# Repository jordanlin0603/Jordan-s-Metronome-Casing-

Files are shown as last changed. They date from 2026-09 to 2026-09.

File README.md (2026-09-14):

# Jordan's Metronome Casing

A custom SolidWorks enclosure designed for [Morgan's Metronome v1.0](https://github.com/morganwang7777-ux/Morgan-s-Metronome-v1.0).

This project focuses on the mechanical design of the metronome enclosure. The casing houses the main PCB and secondary plate, provides clearance for internal wiring, and uses movable retaining rails to keep the electronics secured while still allowing the PCB to be removed for maintenance.

The enclosure was first explored in AutoCAD before being rebuilt and developed more extensively in SolidWorks.

---

# Final Design

The final casing includes:

- Tapered SolidWorks enclosure
- **100 mm × 90 mm × 30 mm** main PCB cavity
- **71 mm × 55 mm × 15 mm** secondary plate slot
- Wiring-clearance pocket
- Through-enclosure wiring passage
- Two movable PCB retaining rails
- M3 screw-compatible pivot points
- Mechanical stops for the retaining rails
- Removable access to the PCB and internal components

Final design reference: **Solidworks 15**

All SolidWorks design images can be found under:

`Design Progress/SolidWorks`

---

# Design Origin

This enclosure was designed specifically for:

## Morgan's Metronome v1.0

https://github.com/morganwang7777-ux/Morgan-s-Metronome-v1.0

Morgan's project contains the electronic portion of the metronome, including:

- Arduino firmware
- KiCad schematic
- PCB layout
- Gerber manufacturing files
- Metronome electronics
- Controls and display
- Supporting project documentation

This repository focuses on the **mechanical casing, internal mounting geometry, wire routing, and PCB retention system** for that project.

---

# SolidWorks Design Process

The final casing was developed over five main SolidWorks design sessions.

## Day 1 — Main Enclosure and PCB Cavity

Created the tapered metronome body and main PCB cavity.

Design references:

- **Solidworks 1** — Main enclosure
- **Solidworks 2** — PCB cavity

---

## Day 2 — Secondary Plate and Wiring Clearance

Added the secondary plate slot, wiring clearance pocket, and through-enclosure wiring passage.

Design references:

- **Solidworks 3** — Plate cavity
- **Solidworks 4** — Secondary plate slot
- **Solidworks 5** — Wiring clearance
- **Solidworks 6** — Wiring passage

---

## Day 3 — Initial PCB Retaining Rail

Designed the original rotating PCB retaining rail and M3 pivot system.

Design references:

- **Solidworks 7** — Initial retaining rail
- **Solidworks 8** — Rail design

---

## Day 4 — Assembly Testing and Retention Redesign

Created a SolidWorks assembly to test the original retaining rail.

Testing showed that placing one rail across the center of the PCB would obstruct access to the PCB controls.

The retention system was redesigned to use separate rails along the **top and bottom edges**, keeping the middle of the PCB accessible.

Design references:

- **Solidworks 9** — Initial assembly
- **Solidworks 10** — Initial rail test
- **Solidworks 11** — Rail redesign
- **Solidworks 12** — Updated assembly
- **Solidworks 13** — Final rail positions

A retaining rail movement test is also included in the SolidWorks folder.

---

## Day 5 — Mechanical Stops and Final Assembly

Added cylindrical mechanical stops to limit the rotation of the retaining rails and completed the final assembly.

Design reference:

- **Solidworks 14** — Mechanical stops

---

# Final Product

The final SolidWorks enclosure combines the PCB cavity, secondary plate cavity, wiring features, movable retaining rails, and mechanical stops into a single mechanical design.

Final design reference:

- **Solidworks 15**

The SolidWorks assembly, design screenshots, and retaining rail motion test can all be found under:

`Design Progress/SolidWorks`

---

# Main Dimensions

| Feature | Dimension |
| --- | --- |
| Enclosure height | 160 mm |
| Bottom width | 140 mm |
| Top width | 100 mm |
| Main PCB cavity | 100 mm × 90 mm × 30 mm |
| Secondary plate slot | 71 mm × 55 mm × 15 mm |
| Wiring clearance pocket | 10 mm × 18 mm × 21 mm |
| Wiring passage | 14 mm × 10 mm |
| Main retaining rail | 125 mm × 12 mm × 4 mm |
| Secondary retaining rail | 110 mm × 12 mm × 4 mm |
| M3 rail clearance hole | Approximately Ø3.2 mm |
| Casing pilot hole | Approximately Ø2.8 mm × 8 mm |

---

# Retaining System

The PCB is held in the rear cavity using two rotating retaining rails.

The original design used one rail across the center of the PCB. SolidWorks assembly testing showed that this would obstruct access to buttons and other PCB components.

The system was redesigned to use separate **top and bottom rails**.

Each rail rotates around an M3 screw pivot, allowing it to swing away during PCB installation or removal and rotate back into position to retain the board.

Mechanical stops were added to limit the rail movement in the closed position.

---

# SolidWorks Tools Used

- Sketch
- Smart Dimension
- Rectangle
- Circle
- Boss-Extrude
- Cut-Extrude
- Assembly
- Insert Components
- Concentric Mate
- Coincident Mate
- Distance Mate

---

# AutoCAD Development

AutoCAD was used during the initial concept stage to explore the basic shape and dimensions of the casing.

The enclosure was later rebuilt in SolidWorks so that parametric dimensions, feature-based modelling, moving components, and assembly mates could be used.

The original AutoCAD development has been kept in this repository to document the progression of the design.

---

# Future Improvements

- 3D print and physically test the enclosure
- Verify PCB and plate tolerances after printing
- Adjust clearances based on the first prototype
- Refine wire routing and connector access
- Add fillets or chamfers where useful
- Improve the mechanical rail stops
- Consider heat-set inserts for repeated screw removal
- Refine the exterior finish of the enclosure

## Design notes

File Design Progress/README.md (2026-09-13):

# AutoCAD Design Progress

## Day 1 — Initial Casing Development

During the first day, I familiarized myself with several fundamental AutoCAD commands and began developing the initial geometry for the metronome casing.

### Work Completed

- Practiced fundamental AutoCAD modelling commands and workflows.
- Created 2D rectangular profiles using the `RECTANG` command.
- Developed 3D rectangular geometry using the `BOX` command.
- Used the `SUBTRACT` command to remove material and create a hollow enclosure.
- Developed the initial outer geometry of the metronome casing.
- Created a rectangular opening on the rear of the casing to accommodate the PCB.

### Progress Photos

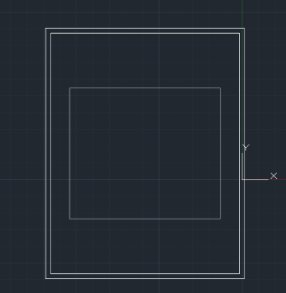
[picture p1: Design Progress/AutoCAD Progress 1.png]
Day 1 - Progress 1


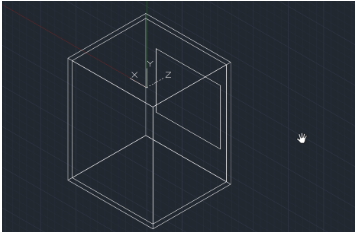
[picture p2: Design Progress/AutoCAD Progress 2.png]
Day 1 - Progress 2


---

## Day 2 — PCB Integration

The second day focused on modifying the casing to accommodate the PCB and improving the design for component integration.

### Work Completed

- Created a 50 mm deep 100mm x 90mm slot within the casing to allow the PCB to be inserted.
- Positioned the slot to provide access for PCB installation while maintaining the overall casing structure.
- Continued refining the casing geometry to support the integration of the electronic components.

### Progress Photo

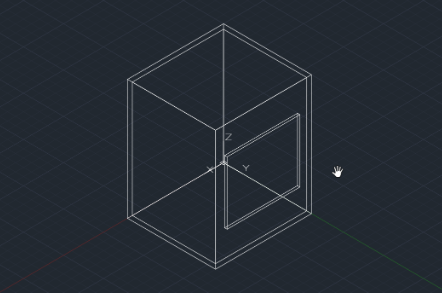
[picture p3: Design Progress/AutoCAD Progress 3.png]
Day 2 - Progress 3


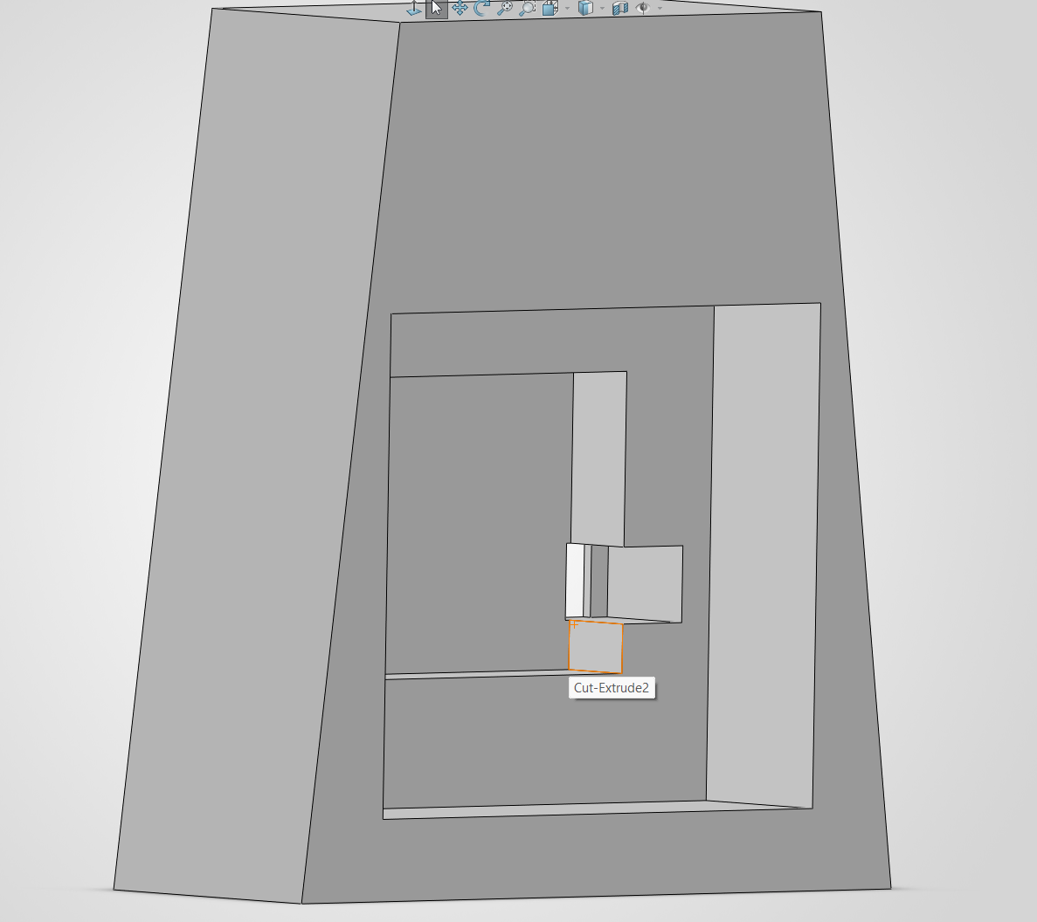
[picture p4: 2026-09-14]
Design Progress/SolidWorks/Solidworks 6.png

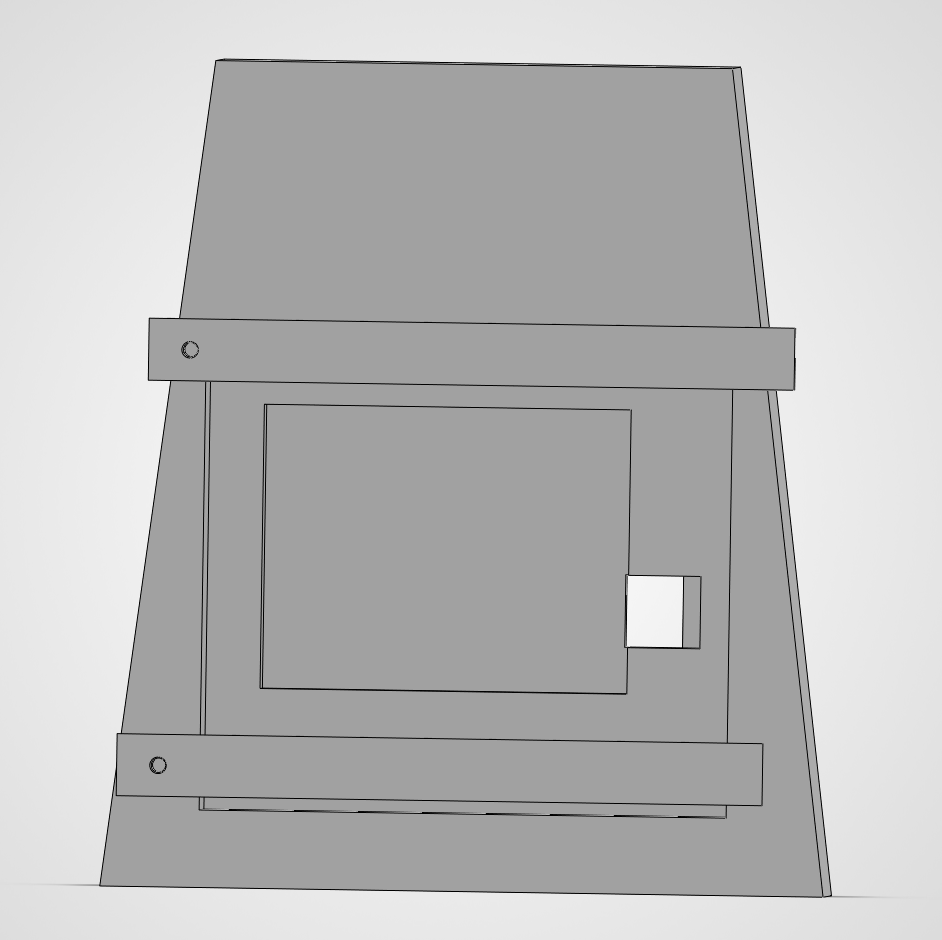
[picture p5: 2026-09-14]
Design Progress/SolidWorks/Solidworks 11.png

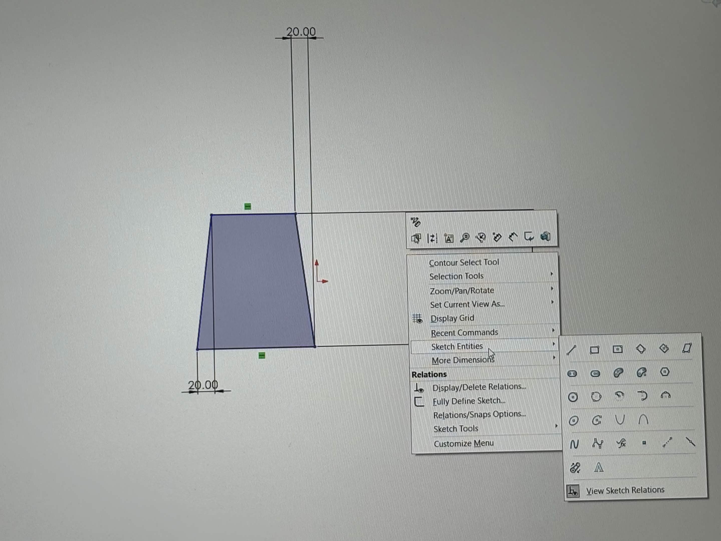
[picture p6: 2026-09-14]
Design Progress/SolidWorks/Solidworks 1.jpg

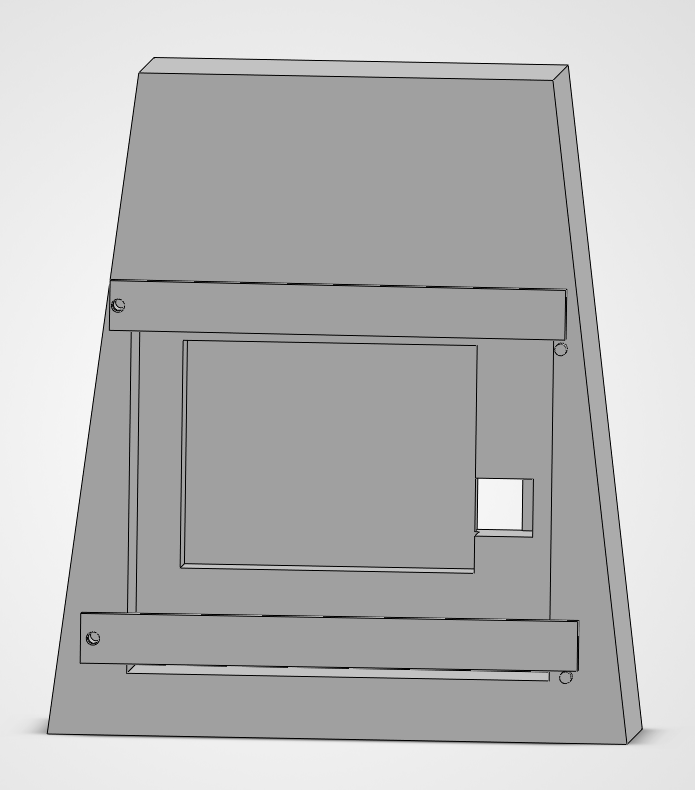
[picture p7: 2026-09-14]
Final Design/Solidworks 15.png

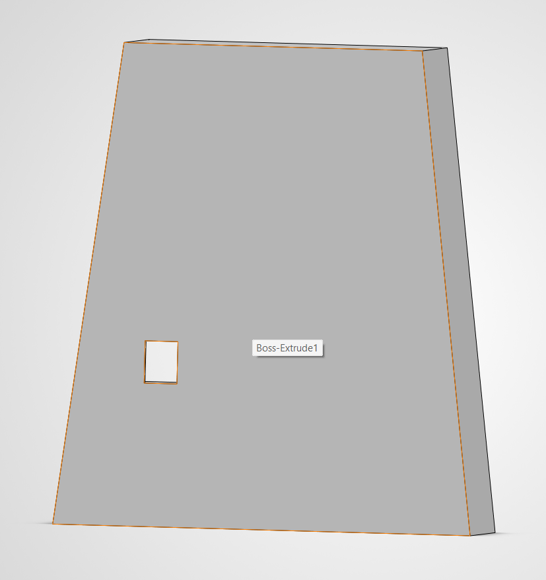
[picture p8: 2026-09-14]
Design Progress/SolidWorks/Solidworks 4.png

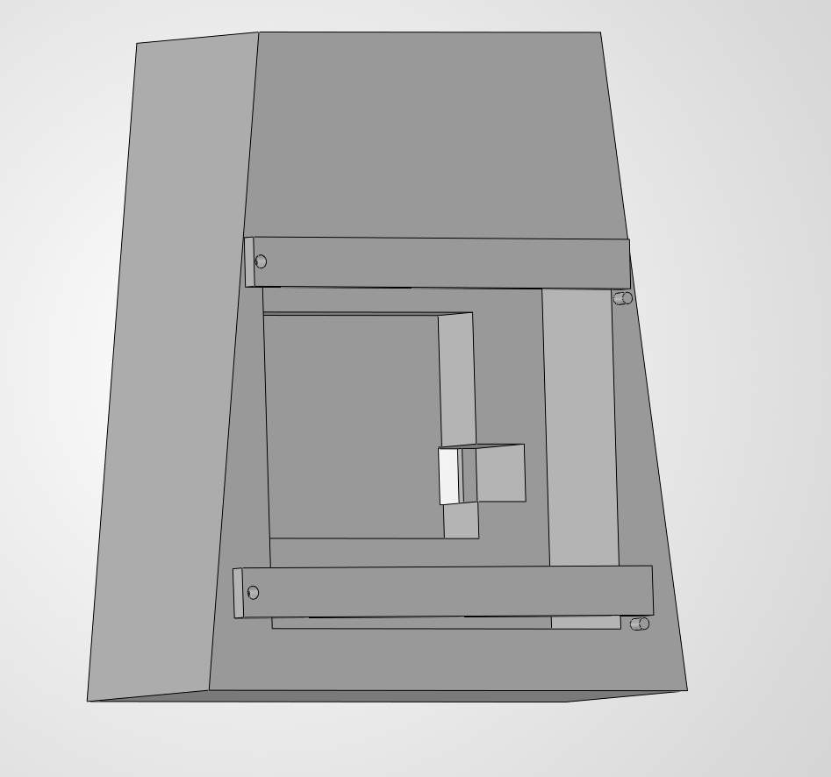
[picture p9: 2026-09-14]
Final Design/Metronome Left Angle.png

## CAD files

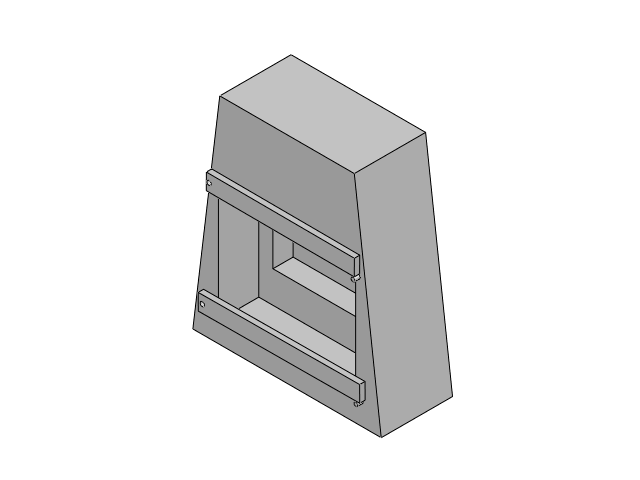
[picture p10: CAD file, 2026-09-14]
Final Design/Metronome Casing Complete.SLDASM
Metronome Design
Metronome Casing Retaining Bar
Metronome Casing Retaining Bar 2
Hitch x 2
